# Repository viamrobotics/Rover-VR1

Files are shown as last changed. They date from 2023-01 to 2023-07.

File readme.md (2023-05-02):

# Viam Rover CAD files and BOM

This repo contains the CAD files (in Solidworks format) and bill-of-materials (BOM) relating to the Viam Rover. 

The CAD folder contains SLDPRT files, DXF files of 2D sheet metal components and a [full assembly in STEP format](https://github.com/viamrobotics/VR1-22-A001/blob/master/CAD/VR1-22-A001.STEP). You can also find the STL assembly of the Viam Rover [here](https://drive.google.com/file/d/1zAmt8tSdFXghSNv3OntW627MksGu3Onb/view?usp=share_link).

For documentation on the Viam Rover unboxing and setup visit [here](https://docs.viam.com/try-viam/rover-resources/rover-tutorial/).

## License 
Copyright 2022-2023 Viam Inc.

Apache 2.0 - See [LICENSE](./LICENSE) file

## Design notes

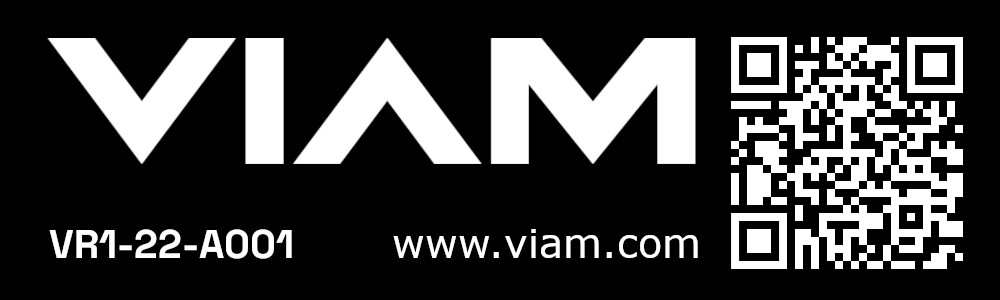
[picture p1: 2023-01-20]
viamlabel.jpg

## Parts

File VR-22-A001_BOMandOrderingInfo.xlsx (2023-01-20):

Part No | Component | Qty | Manufacturer Prt No | Replacement (link as of 1/19/2023)
VR1-22-0001 | Top plate | 1 | Custom | Laser cut from drawing
VR1-22-0002 | Bottom plate | 1 | Custom | Laser cut from drawing
VR1-22-0003 | Battery plate | 1 | Custom | Laser cut from drawing
VR1-22-0004 | Plate standoffs M4 x 70mm | 4 | Custom | Custom/3D print
VR1-22-0005 | Long motor standoffs M4 x 26mm | 4 | Custom | Custom/3D print
VR1-22-0006 | Short motor standoffs M4 x 15mm | 2 | Custom | Custom/3D print
VR1-22-0007 | Right motor unit | 1 | iSweep3 | https://www.alibaba.com/product-detail/ISWEEP-X3-Robot-Vacuum-Wheels-Vacuum_1600097468293.html
VR1-22-0008 | Left motor unit | 1 | iSweep3 | https://www.alibaba.com/product-detail/ISWEEP-X3-Robot-Vacuum-Wheels-Vacuum_1600097468293.html
VR1-22-0009 | Caster | 1 | BCHC40 | https://us.misumi-ec.com/vona2/detail/110302279320/?HissuCode=BCHC40
VR1-22-0010 | Camera | 1 | WB100 | https://www.amazon.com/Webcam-Microphone-Correction-Streaming-YouTube/dp/B0B1TC225T?s=electronics
VR1-22-0011 | Camera mount | 1 | Custom | Custom/3D print
VR1-22-0012 | Battery pack | 1 | Standard | https://www.alibaba.com/product-detail/4-x18650-14-8V-Battery-Holder_1600334741093.html
VR1-22-0013 | Battery pack standoffs M3 x 18mm | 4 | Custom | Custom/3D print
VR1-22-0014 | Electronics standoffs M2.5 x 7mm | 10 | Custom | Custom/3D print
VR1-22-0015 | Switch | 1 | PA000047 | https://www.amazon.com/Magic-shell-5-Pack-Rocker-Position/dp/B07D27P9GV
VR1-22-0016 | Power connector | 1 | DC-A-F | https://www.amazon.com/gp/product/B07C7VSRBG/ref=ppx_yo_dt_b_search_asin_title?ie=UTF8&psc=1
VR1-22-0017 | Buck converter | 1 | mini560 | https://www.amazon.com/DKARDU-Efficiency-Step-Down-stabilized-Converter/dp/B0BGR4FQ8G?s=electronics
VR1-22-0018 | Motor driver | 1 | OKY3195 | https://www.amazon.com/Controller-H-Bridge-Stepper-Control-Mega2560/dp/B07WS89781?s=electronics
VR1-22-0019 | Accelerometer | 1 | ADXL345 | https://www.amazon.com/SunFounder-Digital-Accelerometer-ADXL345-Raspberry/dp/B0151FIBZO?s=electronics
VR1-22-0020 | Jumper wires | 8 | Standard | https://www.amazon.com/EDGELEC-Breadboard-Optional-Assorted-Multicolored/dp/B07GD2BWPY?s=electronics
VR1-22-0021 | Adhesive pad | 2 | Standard | Custom
VR1-22-0022 | Red jumper wire | 1 | Custom | Custom
VR1-22-0023 | Black jumper wire | 1 | Custom | Custom
VR1-22-0024 | M2.5 x 5mm machine screw | 20 | Standard | Standard hardware
VR1-22-0025 | M3 x 8mm machine screw | 12 | Standard | Standard hardware
VR1-22-0026 | M3 x 20mm machine screw | 1 | Standard | Standard hardware
VR1-22-0027 | M4 x 5mm machine screw | 20 | Standard | Standard hardware
VR1-22-0028 | M2.5 nut | 2 | Standard | Standard hardware
VR1-22-0029 | M3 nut | 5 | Standard | Standard hardware
VR1-22-0030 | M2.5 x 8mm machine screw | 2 | Standard | Standard hardware
VR1-22-0031 | High k suspension spring | 2 | iSweep3 | N/A
VR1-22-0032 | Low k suspension spring | 2 | Custom | Custom
VR1-22-0033 | Top sticker | 1 | Custom | Custom
VR1-22-0034 | Bottom sticker | 1 | Custom | Custom
VR1-22-0035 | Raspberry Pi 4 | 1 | rPi4 | See Rplocator
VR1-22-0036 | Red jumper wire 180mm | 1 | Standard | https://www.amazon.com/EDGELEC-Breadboard-Optional-Assorted-Multicolored/dp/B07GD2BWPY?s=electronics
VR1-22-0037 | Black jumper wire 180mm | 1 | Standard | https://www.amazon.com/EDGELEC-Breadboard-Optional-Assorted-Multicolored/dp/B07GD2BWPY?s=electronics
VR1-22-0038 | Red jumper wire 160mm | 1 | Standard | https://www.amazon.com/EDGELEC-Breadboard-Optional-Assorted-Multicolored/dp/B07GD2BWPY?s=electronics
VR1-22-0039 | Black jumper wire 160mm | 1 | Standard | https://www.amazon.com/EDGELEC-Breadboard-Optional-Assorted-Multicolored/dp/B07GD2BWPY?s=electronics
VR1-22-0040 | Red jumper wire 75mm | 2 | Standard | https://www.amazon.com/EDGELEC-Breadboard-Optional-Assorted-Multicolored/dp/B07GD2BWPY?s=electronics
VR1-22-0041 | Blue jumper wire 75mm | 2 | Standard | https://www.amazon.com/EDGELEC-Breadboard-Optional-Assorted-Multicolored/dp/B07GD2BWPY?s=electronics
VR1-22-0042 | White jumper wire 220mm | 1 | Standard | https://www.amazon.com/EDGELEC-Breadboard-Optional-Assorted-Multicolored/dp/B07GD2BWPY?s=electronics
VR1-22-0043 | Red jumper wire 220mm | 1 | Standard | https://www.amazon.com/EDGELEC-Breadboard-Optional-Assorted-Multicolored/dp/B07GD2BWPY?s=electronics
VR1-22-0044 | Black jumper wire 220mm | 1 | Standard | https://www.amazon.com/EDGELEC-Breadboard-Optional-Assorted-Multicolored/dp/B07GD2BWPY?s=electronics
VR1-22-0045 | Yellow jumper wire 220mm | 1 | Standard | https://www.amazon.com/EDGELEC-Breadboard-Optional-Assorted-Multicolored/dp/B07GD2BWPY?s=electronics
VR1-22-0046 | Red switch wire 180mm + terminal | 1 | Standard | Standard hardware
VR1-22-0047 | Terminal | 1 | Standard | Standard hardware
VR1-22-0048 | PCB w/ resistors | 1 | Standard | Custom
VR1-22-0049 | PCB standoffs | 2 | Standard | Standard hardware

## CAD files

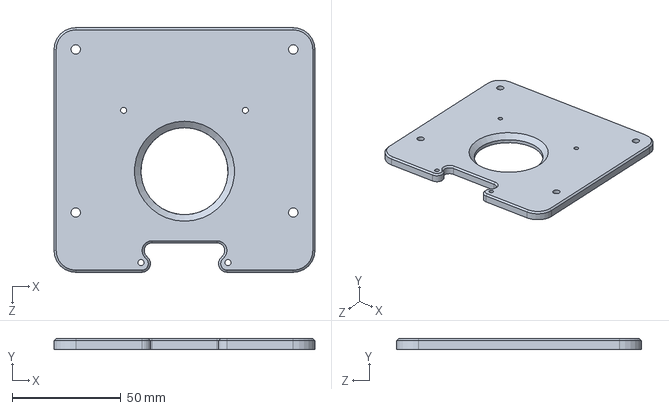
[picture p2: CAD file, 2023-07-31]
CAD/RPIidarA1_adapter.SLDPRT
120.0 x 5.00 x 112.5 mm

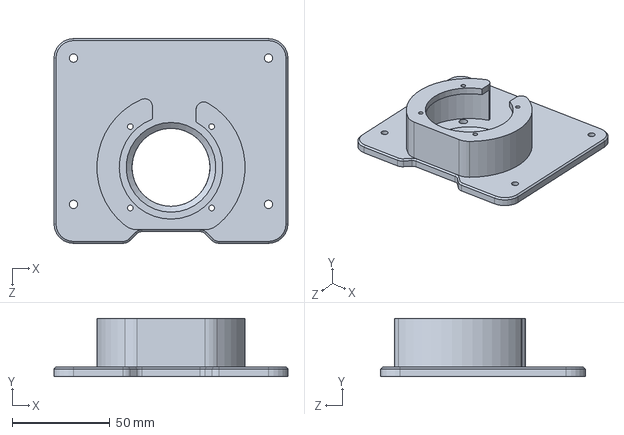
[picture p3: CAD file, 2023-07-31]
CAD/RPIidarA3_adapter.SLDPRT
120.0 x 30.0 x 105.0 mm

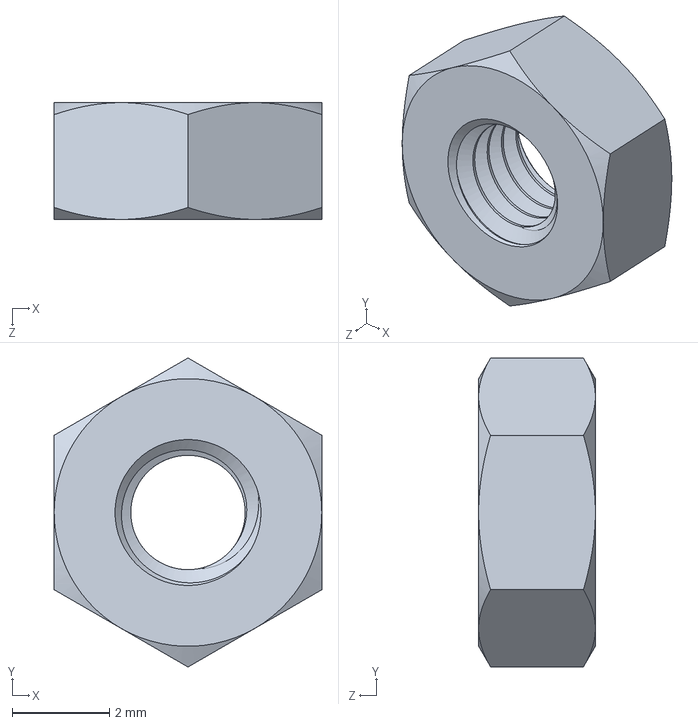
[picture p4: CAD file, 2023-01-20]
CAD/VR1-22-0029.SLDPRT
5.50 x 6.35 x 2.40 mm

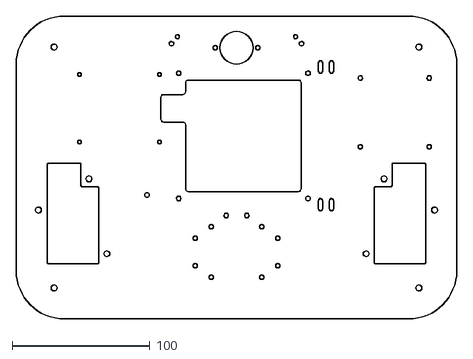
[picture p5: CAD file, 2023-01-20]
CAD/VR1-22-0002A.DXF
320.0 x 220.0

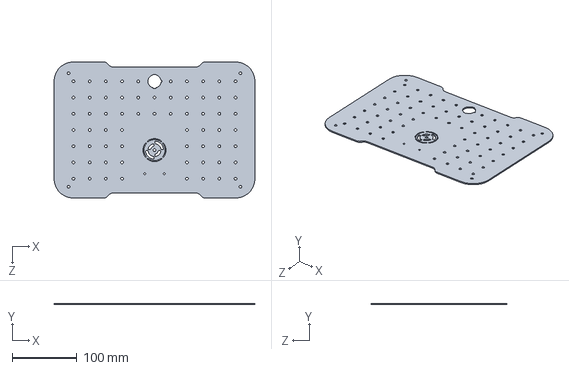
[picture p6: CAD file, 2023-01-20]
CAD/VR1-22-0001.SLDPRT
310.0 x 2.00 x 210.0 mm

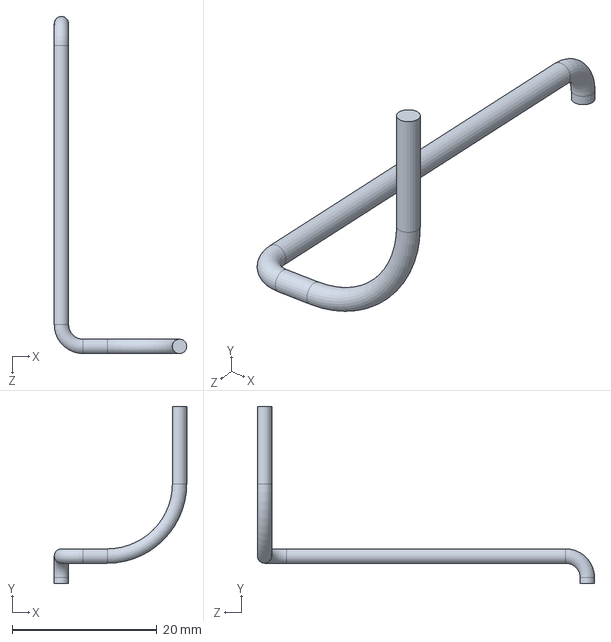
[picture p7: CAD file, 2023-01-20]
CAD/VR1-22-0022.SLDPRT
18.3 x 24.5 x 46.7 mm

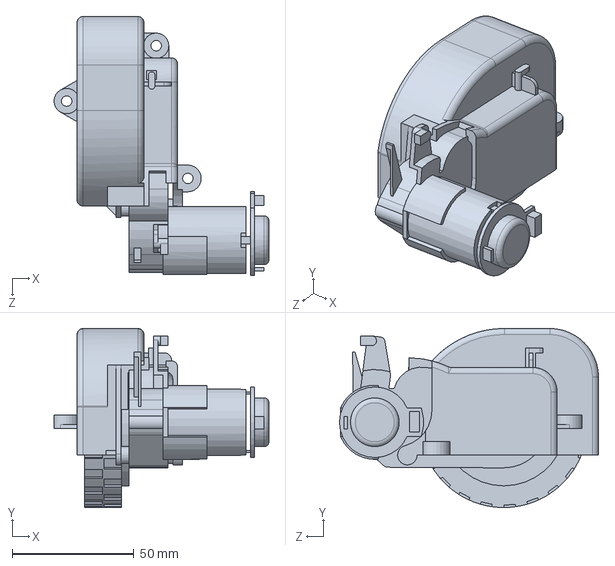
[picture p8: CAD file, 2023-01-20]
CAD/VR1-22-0007.SLDPRT
88.2 x 73.5 x 106.3 mm

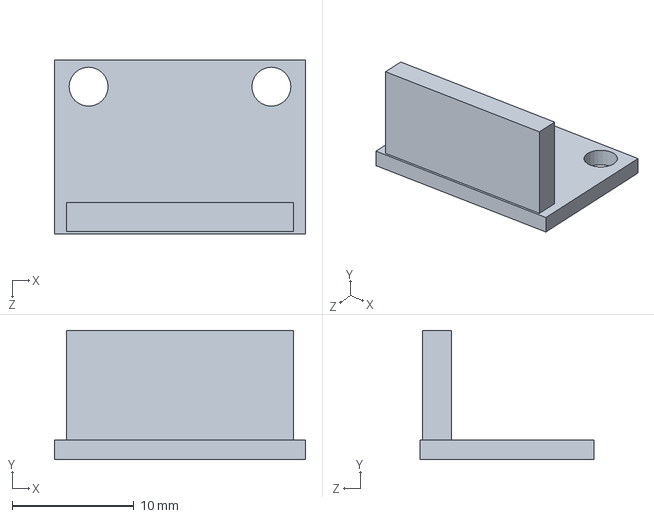
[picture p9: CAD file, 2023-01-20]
CAD/VR1-22-0019.SLDPRT
20.6 x 10.6 x 14.3 mm

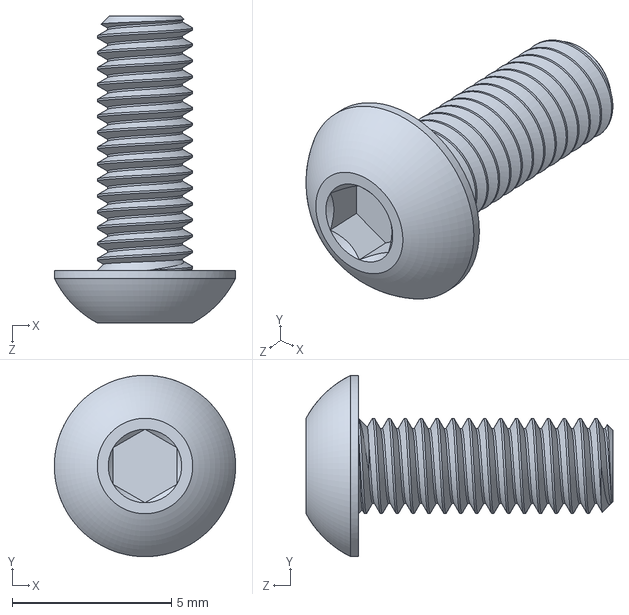
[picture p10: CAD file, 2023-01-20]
CAD/VR1-22-0025.SLDPRT
5.70 x 5.70 x 9.65 mm

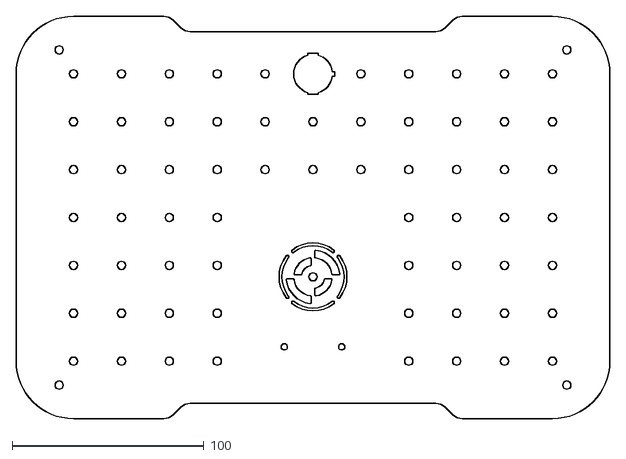
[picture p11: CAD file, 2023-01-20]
CAD/VR1-22-0001A.DXF
310.0 x 210.0

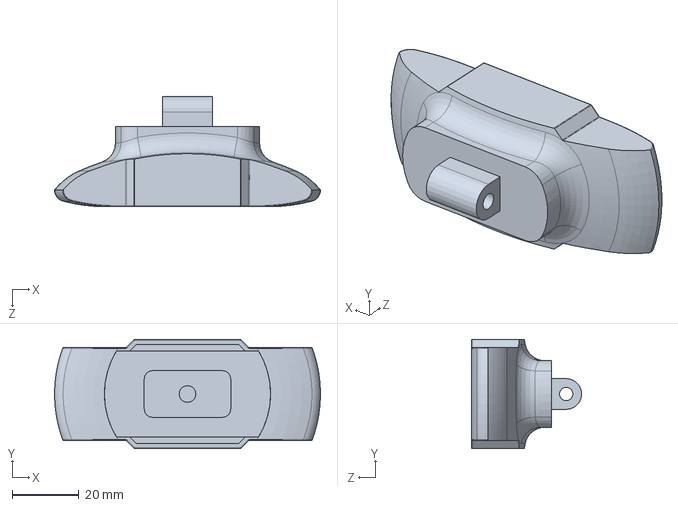
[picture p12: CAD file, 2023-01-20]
CAD/VR1-22-0010.SLDPRT
79.9 x 32.8 x 33.1 mm

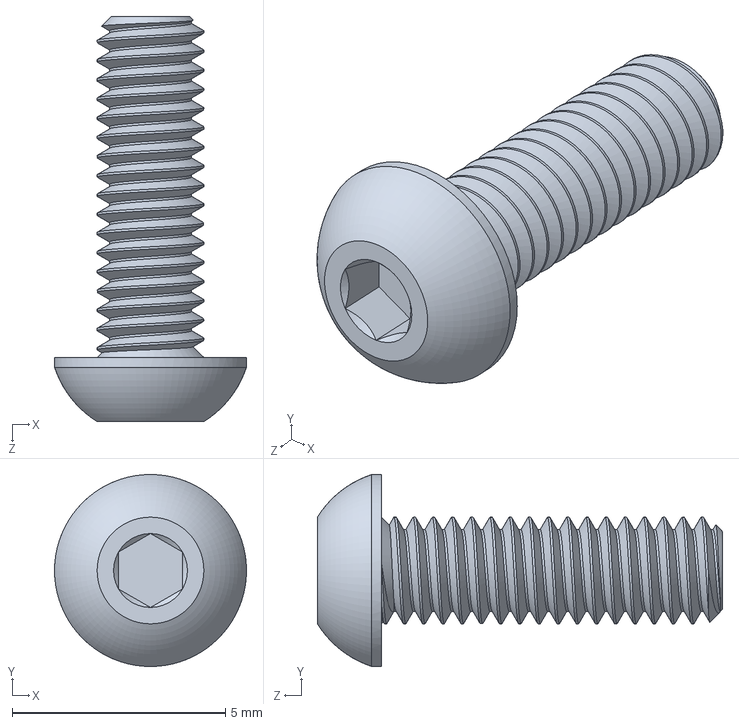
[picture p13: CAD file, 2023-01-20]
CAD/VR1-22-0030.SLDPRT
4.50 x 4.50 x 9.50 mm

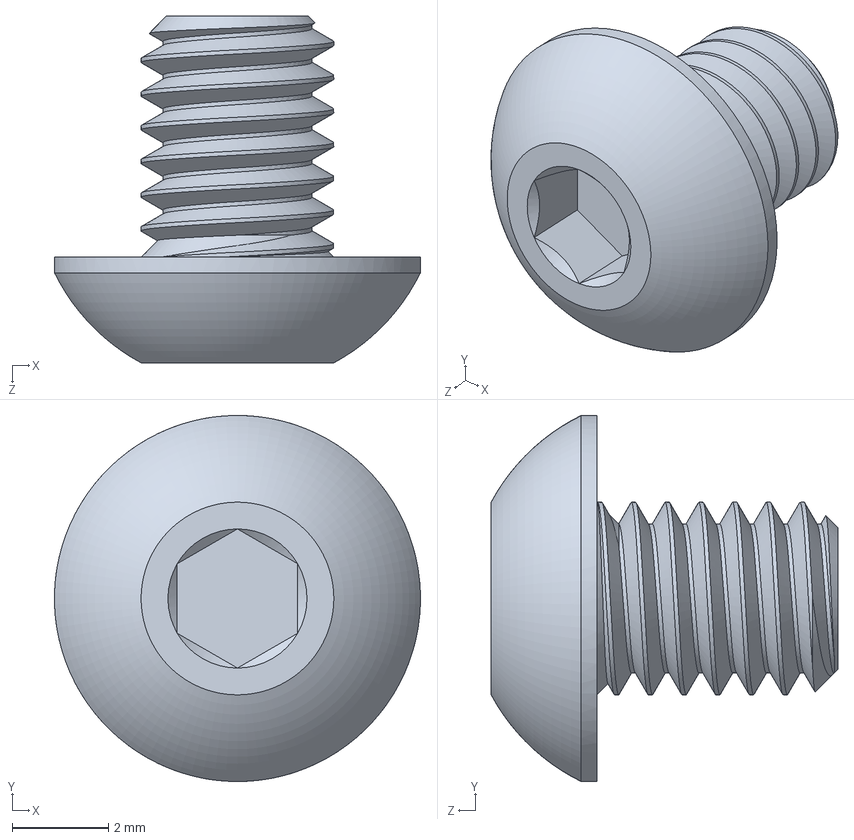
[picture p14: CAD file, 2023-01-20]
CAD/VR1-22-0027.SLDPRT
7.60 x 7.60 x 7.20 mm

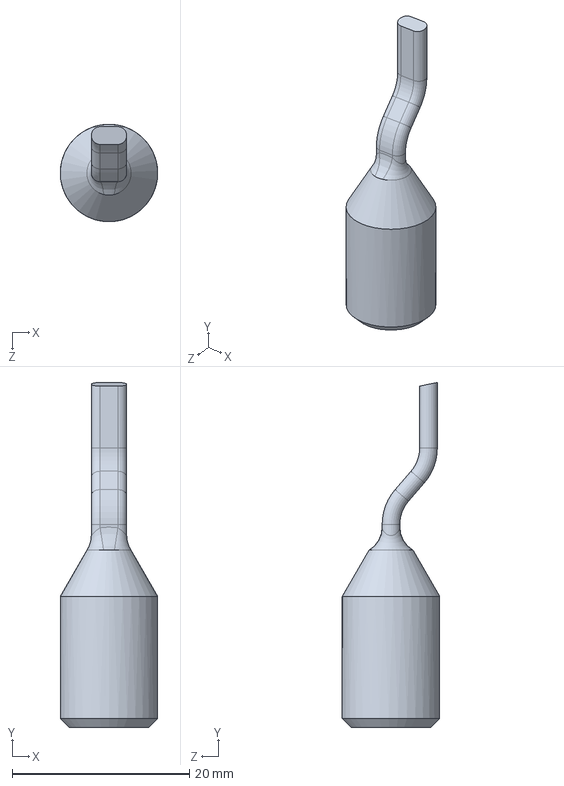
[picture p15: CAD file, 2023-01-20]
CAD/VR1-22-0016.SLDPRT
11.0 x 38.9 x 11.0 mm

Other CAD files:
CAD/VR1-22-0006.SLDPRT
CAD/VR1-22-0003.SLDPRT
CAD/VR1-22-0005.SLDPRT
CAD/VR1-22-0026.SLDPRT
CAD/RPIidarA1_adapter.STL
CAD/RPIidarA3_adapter.STL
CAD/VR1-22-0002.SLDPRT
CAD/VR1-22-0003.DXF
CAD/VR1-22-0004.SLDPRT
CAD/VR1-22-0008.SLDPRT
CAD/VR1-22-0009.SLDPRT
CAD/VR1-22-0011-3dprintversion.SLDPRT
CAD/VR1-22-0011.SLDPRT
CAD/VR1-22-0011_unfold.SLDPRT
CAD/VR1-22-0012.SLDPRT
CAD/VR1-22-0013.SLDPRT
CAD/VR1-22-0014.SLDPRT
CAD/VR1-22-0015.SLDPRT
CAD/VR1-22-0017.SLDPRT
CAD/VR1-22-0018.SLDPRT
CAD/VR1-22-0021.SLDPRT
CAD/VR1-22-0024.SLDPRT
CAD/VR1-22-0028.SLDPRT
CAD/VR1-22-0031.SLDPRT
CAD/VR1-22-0031e.SLDPRT
CAD/VR1-22-0033.DXF
CAD/VR1-22-0033.SLDPRT

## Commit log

2023-01-20 Components and BOM for Viam Rover
    [VR-22-A001_BOMandOrderingInfo.xlsx, VR1-22-0001.SLDPRT, VR1-22-0001A.DXF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]
2023-03-22 Adding RPLidar adapter CAD
    [RPIidar_adapter.SLDPRT, RPIidar_adapter.STL]
2023-03-22 Adding CAD to folder
    [RPIidar_adapter.SLDPRT, RPIidar_adapter.STL, VR1-22-0001.SLDPRT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]
